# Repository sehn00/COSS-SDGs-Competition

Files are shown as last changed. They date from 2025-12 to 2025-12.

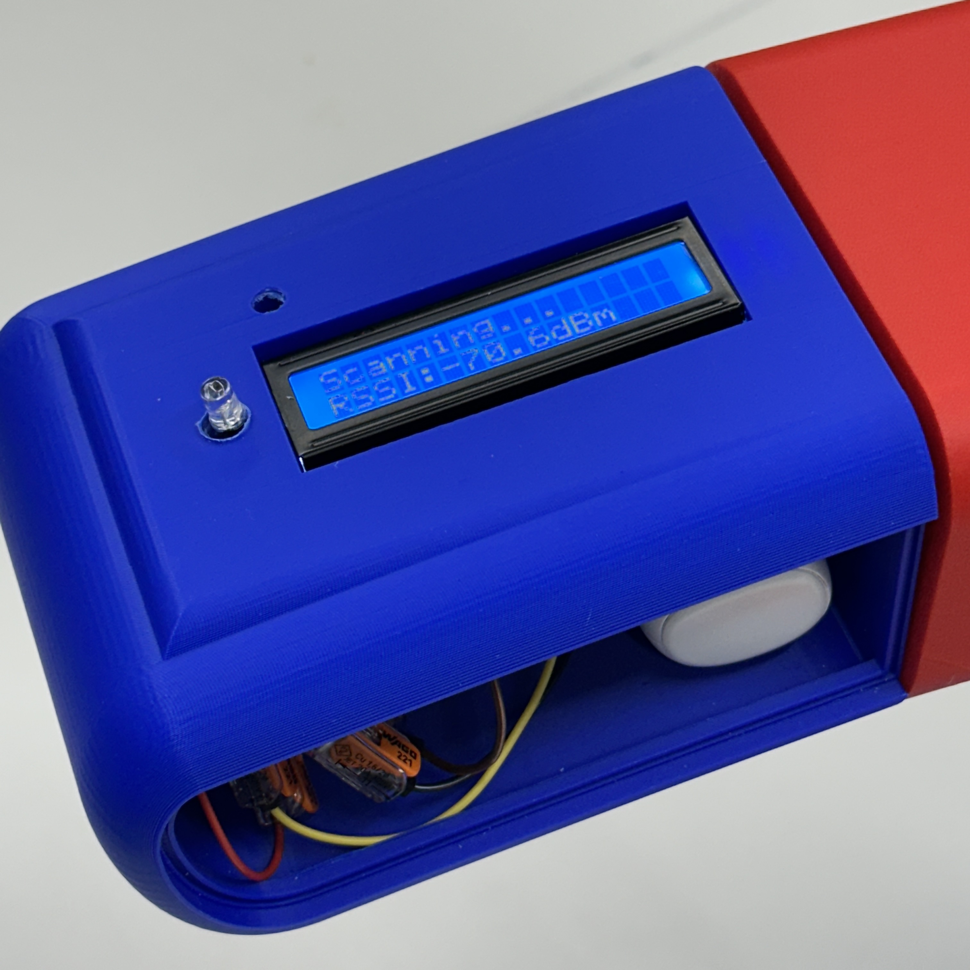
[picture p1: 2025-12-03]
images/04_assembly_receiver_module.jpg

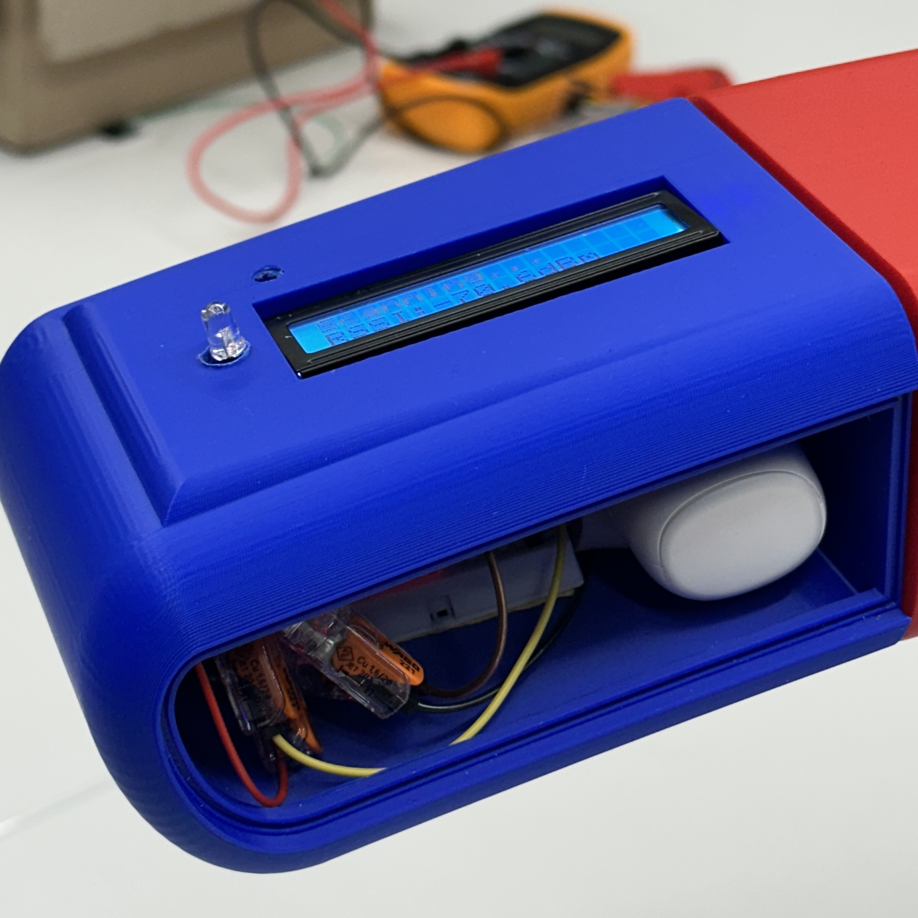
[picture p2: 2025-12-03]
images/05_assembly_receiver_module_side.jpg

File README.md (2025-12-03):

# COSS-SDGs-Competition
2025 COSS SDGs 기반 사회문제 해결 경진대회 대상(1위) 수상작  


<br>

## 비접촉형 교통약자 배려 시스템 (Non-Contact Priority System)
### *COSS SDGs 사회문제 해결 경진대회(중앙대학교) — 대상(1위) 수상 프로젝트*

고령자·임산부·장애인 등 교통약자가 **양보 요청을 직접 하기 어려운 문제**를 해결하기 위해 개발한 비접촉식 인지·알림 시스템  
ESP32 RSSI 기반 거리 판단 + 장치 내장 LED/진동/LCD 표시를 통해 **소음 없이 자연스럽게 양보를 유도**함  
### Demo Video  
https://youtube.com/watch?v=965nC90RXDw

---

## 🚀 프로젝트 개요

- **근접 감지 자동 인식**  
  ESP32 Wi-Fi RSSI 기반으로 사용자의 위치를 인지하고 거리 구간(FAR, NEAR, TOO CLOSE)으로 분류

- **소음 없는 알림 방식**  
  진동모터, LED, LCD 메시지를 활용하여 자연스럽게 양보 요청

- **3D 프린팅 기반 일체형 디자인**  
  직접 설계한 팔걸이 구조물에 ESP32 + 진동모터 + LCD + 배터리 일체형 내장

- **구조 안전성 검증**  
  Autodesk Fusion에서 500N 하중 가정 변형/응력 시뮬레이션 수행

---

## 🛠 기술 스택

- **Hardware**: ESP32-C3, 진동모터, LCD, 3D 프린팅 하우징  
- **Software**: C/C++ (Arduino, ESP32), ESP-NOW 기반 브로드캐스트 통신, RSSI 평균/임계값 기반 거리 판단 로직  
- **Design/Simulation**: Fusion360 모델링 및 구조해석  

---

## 📡 동작 알고리즘

1. ESP32가 주변 Wi-Fi 패킷 수신  
2. RSSI 측정 → 노이즈 제거 및 평균화  
3. 거리 상태 판별  
   - RSSI < -68 dBm → **FAR**  
   - -68 dBm ≤ RSSI < -53 dBm → **NEAR**  
   - RSSI ≥ -53 dBm → **TOO CLOSE**  
4. 상태에 따라 LED/진동/LCD 메시지를 출력하여 양보 요청

---

## 📈 기대 효과

- 교통약자가 직접 요청하지 않아도 양보 상황을 자연스럽게 유도  
- 버스·지하철 등 공공 교통수단의 배려 좌석 접근성을 개선  
- 상업적/공공기관 연동 시 확장 가능성 높음  

---

## 🏆 수상 내역

- **COSS 주관 SDGs 사회문제 해결 경진대회 – 대상(1위)**  
  (프로젝트명: 비접촉형 교통약자 배려 시스템)

---

## 📜 License

This repository is available for reference and review.

**Copyright (c) 2025. All rights reserved.**  
Copying, modification, redistribution, or reuse of the code or design in this project is **not permitted** without explicit permission from the author.

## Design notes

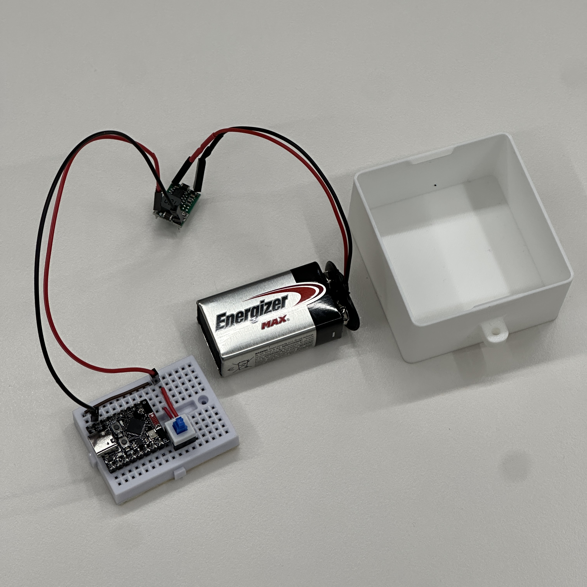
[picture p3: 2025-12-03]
images/03_proto_sender_module.jpg

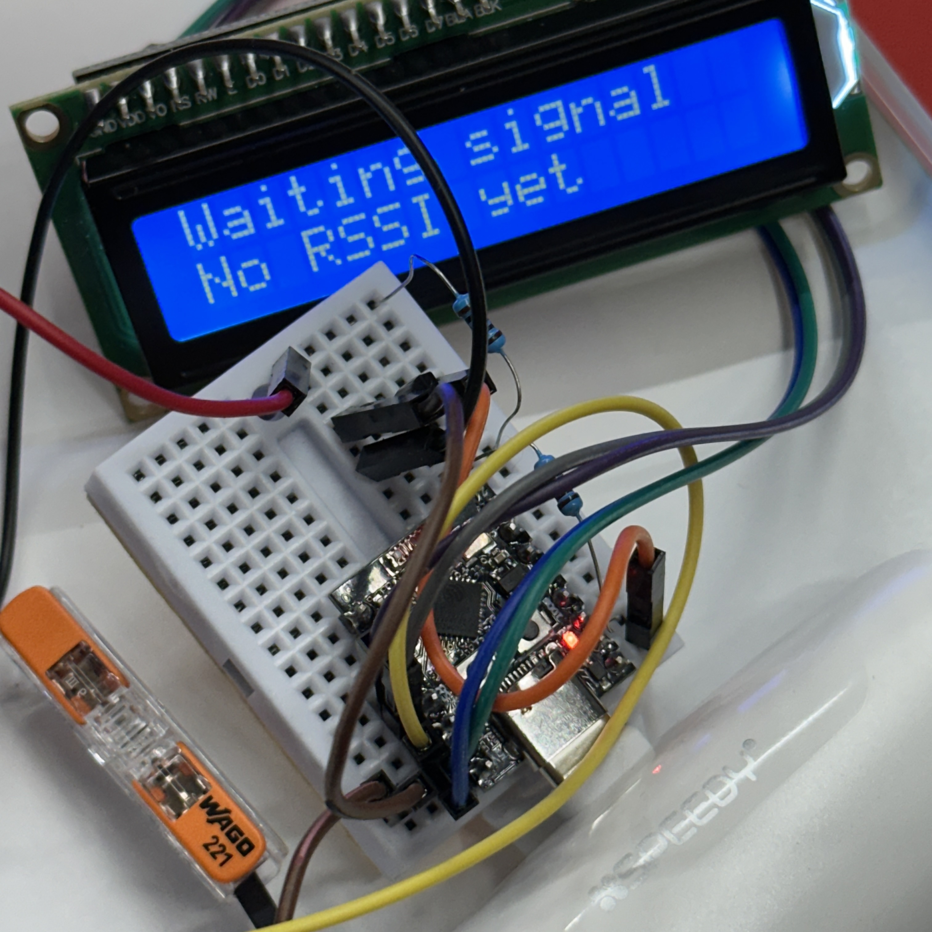
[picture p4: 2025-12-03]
images/01_proto_waiting_signal_close.jpg

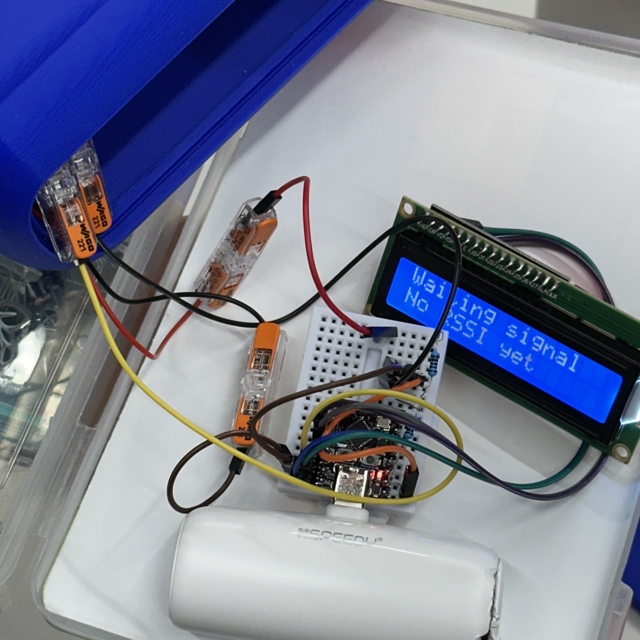
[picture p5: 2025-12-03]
images/02_proto_waiting_signal_full.jpg

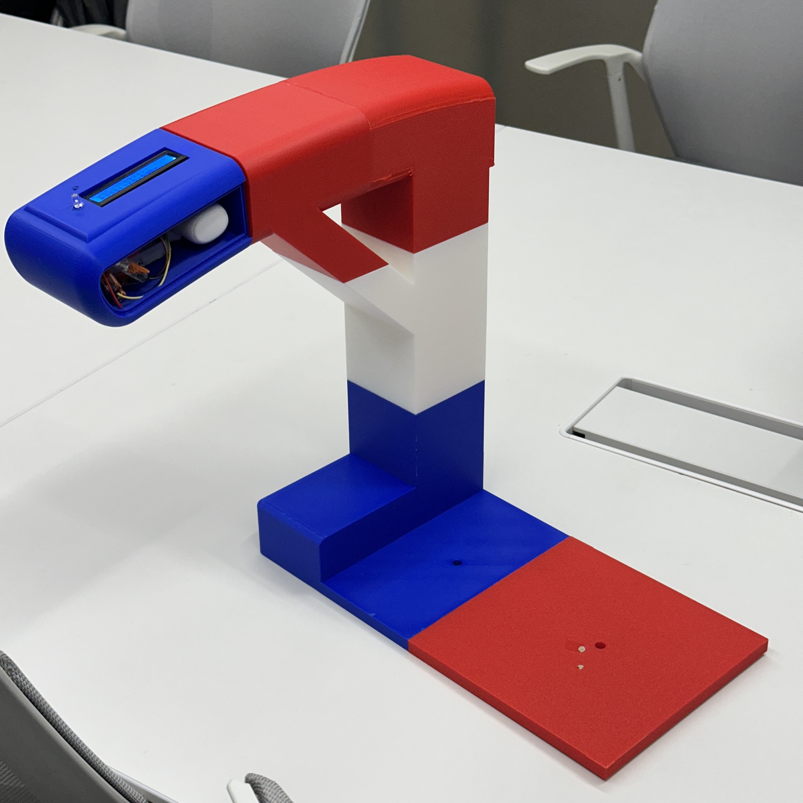
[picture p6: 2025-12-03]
images/06_final_full_device.jpg

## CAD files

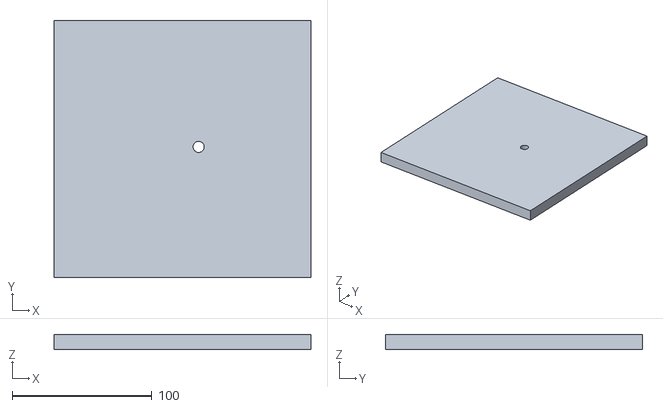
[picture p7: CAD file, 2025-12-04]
3d_prints/arm/bottom2.stl
184.0 x 184.0 x 10.6

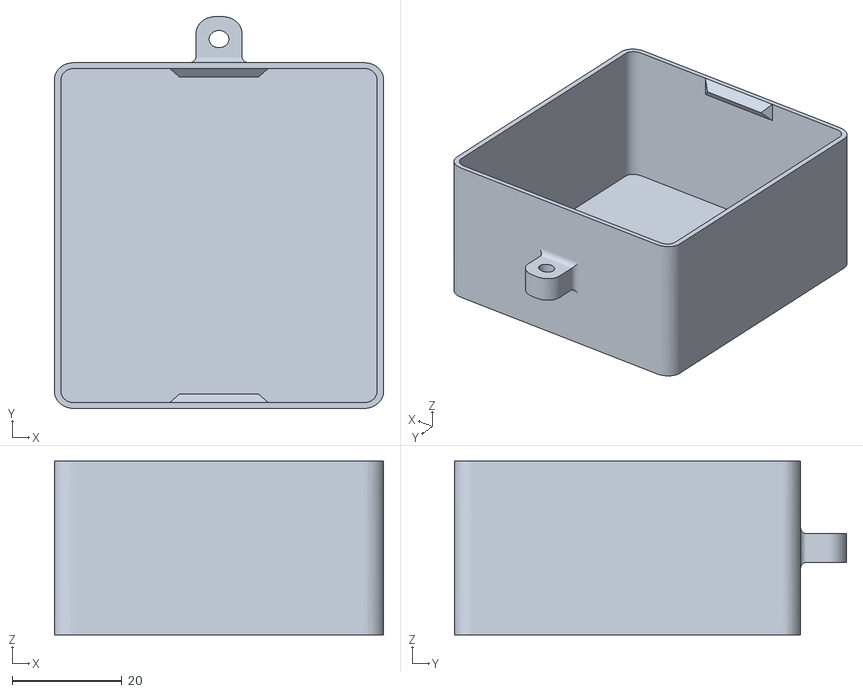
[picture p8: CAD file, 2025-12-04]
3d_prints/badge/badge.stl
60.0 x 71.4 x 31.7

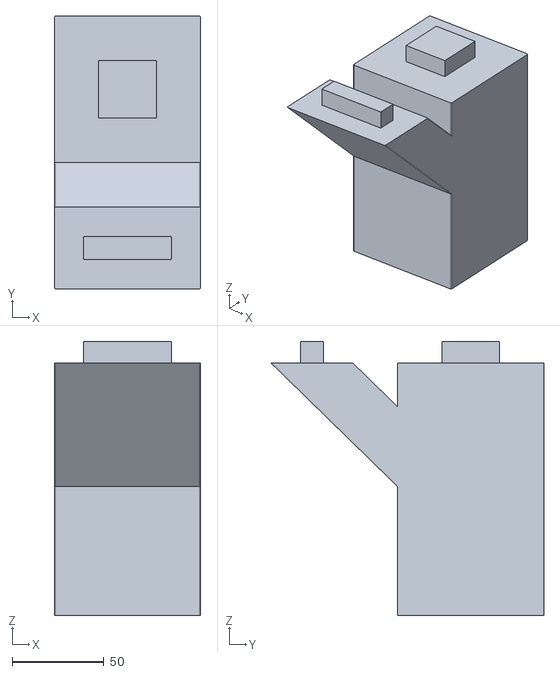
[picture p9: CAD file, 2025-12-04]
3d_prints/arm/body3.stl
80.0 x 149.1 x 149.9

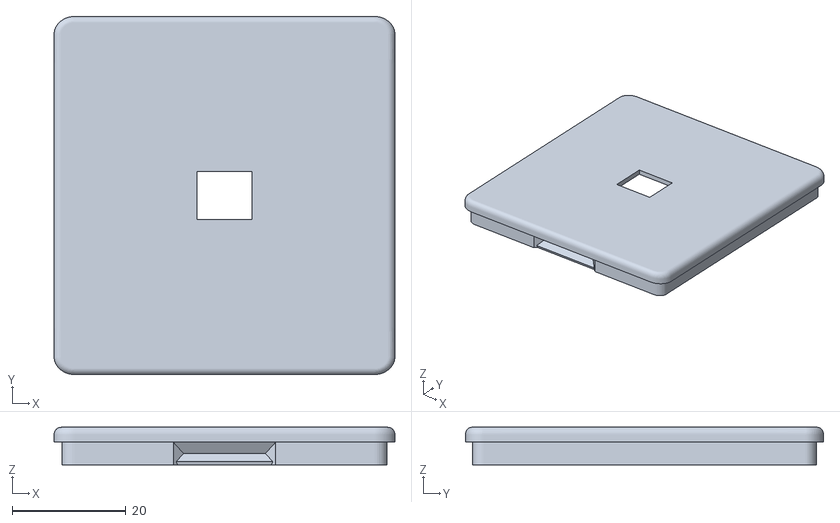
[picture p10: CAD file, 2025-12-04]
3d_prints/badge/badge_cover.stl
60.0 x 63.0 x 6.60

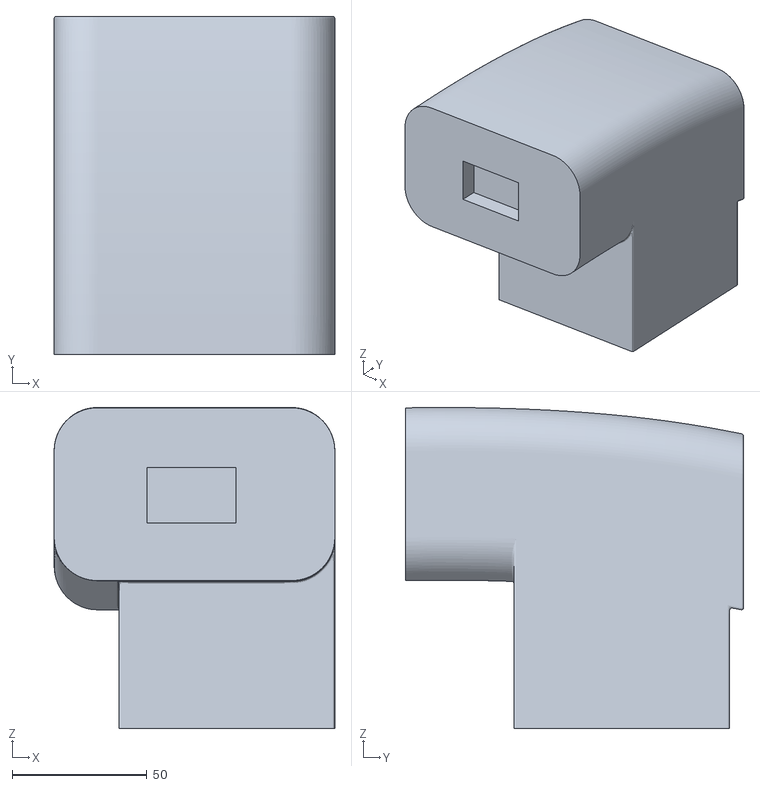
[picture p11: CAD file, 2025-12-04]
3d_prints/arm/body2.stl
104.0 x 125.3 x 118.9

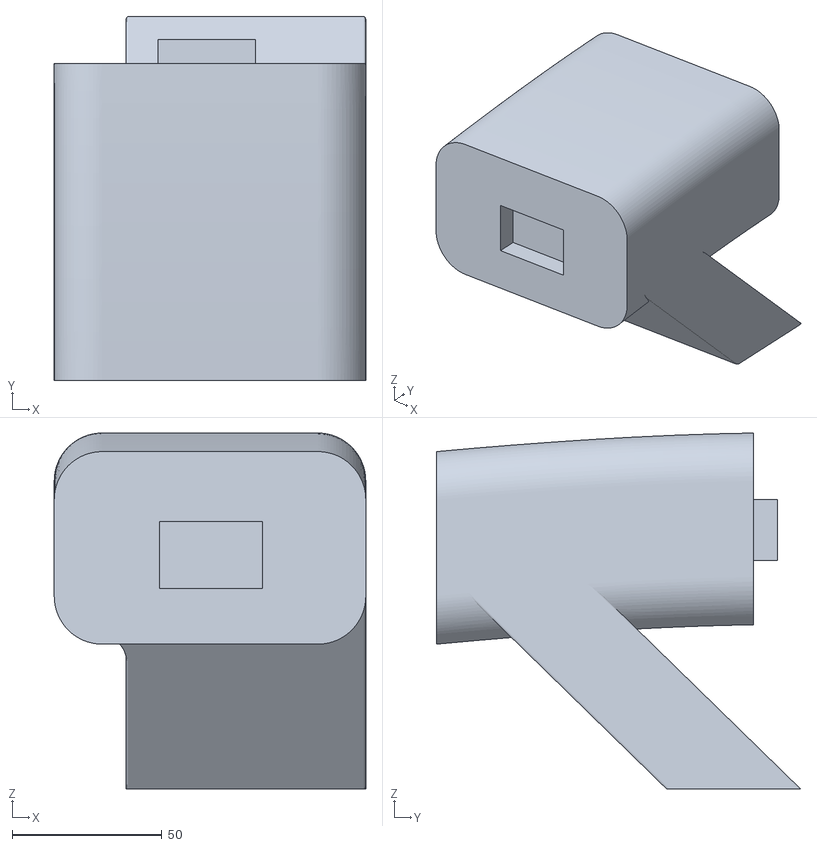
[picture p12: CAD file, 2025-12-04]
3d_prints/arm/body1.stl
104.0 x 121.6 x 118.8

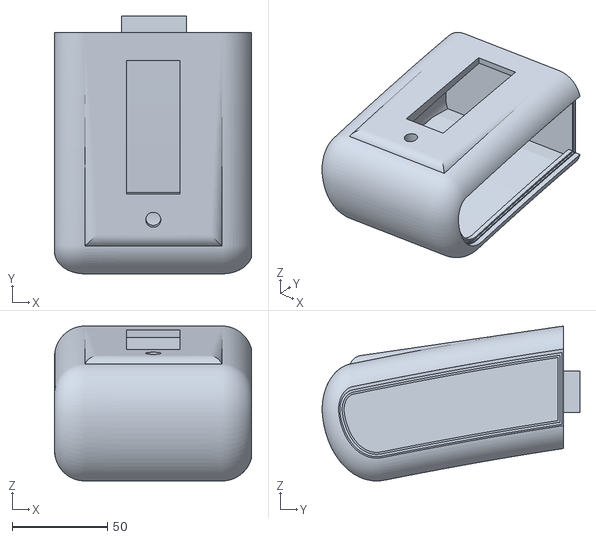
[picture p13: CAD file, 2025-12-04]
3d_prints/arm/module.stl
103.5 x 135.4 x 81.4

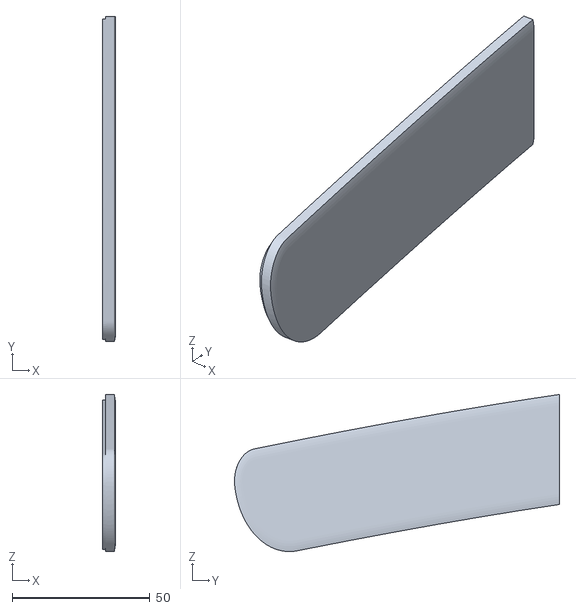
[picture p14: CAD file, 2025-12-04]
3d_prints/arm/cover.stl
4.75 x 117.9 x 57.0

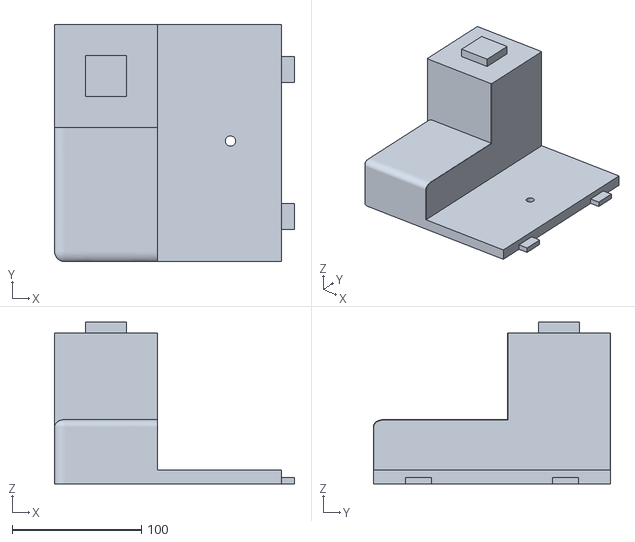
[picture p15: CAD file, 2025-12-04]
3d_prints/arm/bottom1.stl
186.0 x 184.0 x 125.3

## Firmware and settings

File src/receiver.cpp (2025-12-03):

#include <WiFi.h>
#include <esp_now.h>
#include <Wire.h>
#include <LiquidCrystal_I2C.h>

// ==== 핀 설정 ====
const int SDA_PIN = 3;   // I2C LCD - SDA
const int SCL_PIN = 4;   // I2C LCD - SCL

const int LED_PIN = 6;
const int VIB_PIN = 5;   // NPN tr base

LiquidCrystal_I2C lcd(0x27, 16, 2);

uint8_t senderMac[] = {0xB8, 0xF8, 0x62, 0xB4, 0x76, 0xC8};

// ==== RSSI 관련 변수 ====
volatile int   lastRssi = -127;
volatile bool  hasRssi  = false;
float          rssiAvg  = -100.0f;
const float    alpha    = 0.2f;

// ==== 근접/차단 임계값 ====
const int RSSI_NEAR_THRESHOLD   = -68;
const int RSSI_BLOCK_ENTER      = -53;
const int RSSI_BLOCK_EXIT       = -54;

bool tooCloseState = false;

// ==== ESP-NOW 수신 콜백 ====
void onRecv(const esp_now_recv_info* info, const uint8_t* data, int len) {
  if (!info || !info->rx_ctrl) return;

  const uint8_t* mac = info->src_addr;
  for (int i = 0; i < 6; i++) {
    if (mac[i] != senderMac[i]) return;
  }

  int rssi = info->rx_ctrl->rssi;
  lastRssi = rssi;
  hasRssi  = true;

  if (rssiAvg < -99.0f) {
    rssiAvg = (float)rssi;
  } else {
    rssiAvg = alpha * (float)rssi + (1.0f - alpha) * rssiAvg;
  }
}

// ==== 출력 제어 ====
void updateOutputs(bool isNear, bool tooClose, int rssi, float avg, bool has) {
  if (!has) {
    digitalWrite(LED_PIN, LOW);
    digitalWrite(VIB_PIN, LOW);

    lcd.clear();
    lcd.setCursor(0, 0);
    lcd.print("Waiting signal");
    lcd.setCursor(0, 1);
    lcd.print("No RSSI yet");

    Serial.println("NO_SIGNAL");
    return;
  }

  if (tooClose) {
    digitalWrite(LED_PIN, LOW);
    digitalWrite(VIB_PIN, LOW);

    lcd.clear();

    Serial.print("last=");
    Serial.print(rssi);
    Serial.print(" avg=");
    Serial.print(avg, 1);
    Serial.println(" -> TOO_CLOSE");
  }
  else if (isNear) {
    digitalWrite(LED_PIN, HIGH);
    digitalWrite(VIB_PIN, HIGH);

    lcd.clear();
    lcd.setCursor(0, 0);
    lcd.print("PRIORITY SEAT");

    lcd.setCursor(0, 1);
    lcd.print("PLEASE GIVE SEAT");

    Serial.print("last=");
    Serial.print(rssi);
    Serial.print(" avg=");
    Serial.print(avg, 1);
    Serial.println(" -> NEAR");
  }
  else {
    digitalWrite(LED_PIN, LOW);
    digitalWrite(VIB_PIN, LOW);

    lcd.clear();
    lcd.setCursor(0, 0);
    lcd.print("Scanning...");
    lcd.setCursor(0, 1);
    lcd.print("RSSI:");
    lcd.print(avg, 1);
    lcd.print("dBm");

    Serial.print("last=");
    Serial.print(rssi);
    Serial.print(" avg=");
    Serial.print(avg, 1);
    Serial.println(" -> FAR");
  }
}

void setup() {
  Serial.begin(115200);
  delay(2000);

  pinMode(LED_PIN, OUTPUT);
  digitalWrite(LED_PIN, LOW);

  pinMode(VIB_PIN, OUTPUT);
  digitalWrite(VIB_PIN, LOW);

  Wire.begin(SDA_PIN, SCL_PIN);
  lcd.init();
  lcd.backlight();

  WiFi.mode(WIFI_STA);
  esp_now_init();
  esp_now_register_recv_cb(onRecv);
}

void loop() {
  static unsigned long lastUpdate = 0;
  unsigned long now = millis();

  if (now - lastUpdate >= 500) {
    lastUpdate = now;

    int   rssiCopy;
    float avgCopy;
    bool  hasCopy;

    noInterrupts();
    rssiCopy = lastRssi;
    avgCopy  = rssiAvg;
    hasCopy  = hasRssi;
    interrupts();

    if (hasCopy) {
      if (!tooCloseState && avgCopy >= RSSI_BLOCK_ENTER) {
        tooCloseState = true;
      }
      else if (tooCloseState && avgCopy <= RSSI_BLOCK_EXIT) {
        tooCloseState = false;
      }
    }

    bool isNear = (hasCopy && !tooCloseState && avgCopy > RSSI_NEAR_THRESHOLD);
    updateOutputs(isNear, tooCloseState, rssiCopy, avgCopy, hasCopy);
  }
}

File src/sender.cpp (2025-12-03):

#include <WiFi.h>
#include <esp_now.h>

// 브로드캐스트 주소 (모든 ESP-NOW 디바이스에게 전송)
uint8_t broadcastAddr[] = {0xFF, 0xFF, 0xFF, 0xFF, 0xFF, 0xFF};

typedef struct {
  uint32_t counter;
} PingMsg;

PingMsg msg;

void setup() {
  Serial.begin(115200);
  delay(2000);
  Serial.println();
  Serial.println("=== A 보드 (Sender) 시작 ===");

  // ESP-NOW는 STA 모드에서 사용
  WiFi.mode(WIFI_STA);

  if (esp_now_init() != ESP_OK) {
    Serial.println("ESP-NOW init 실패");
    return;
  }
  Serial.println("ESP-NOW init 성공");

  // 브로드캐스트 peer 등록
  esp_now_peer_info_t peer{};
  memcpy(peer.peer_addr, broadcastAddr, 6);
  peer.channel = 0;      // 0 = 현재 채널 사용
  peer.encrypt = false;

  if (esp_now_add_peer(&peer) != ESP_OK) {
    Serial.println("peer 등록 실패");
    return;
  }
  Serial.println("peer 등록 성공, 브로드캐스트 전송 준비 완료");
}

unsigned long lastSend = 0;
const unsigned long SEND_INTERVAL_MS = 500;

void loop() {
  unsigned long now = millis();
  if (now - lastSend >= SEND_INTERVAL_MS) {
    lastSend = now;
    msg.counter++;

    esp_err_t result = esp_now_send(broadcastAddr, (uint8_t*)&msg, sizeof(msg));
    Serial.print("PING 보냄, cnt = ");
    Serial.print(msg.counter);
    Serial.print(" / 결과 = ");
    Serial.println(result == ESP_OK ? "OK" : "ERR");
  }
}
